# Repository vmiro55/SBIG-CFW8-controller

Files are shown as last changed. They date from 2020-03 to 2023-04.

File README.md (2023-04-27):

# SBIG-CFW8-controller
Arduino based controller for the CFW8 filter wheel manufactured by SBIG

The filter wheel will intialized to the first position when powered on.
In this case the first filter is RED. The filters in sequence are Red, Green, Blue, Luminance and an open spot (labeled clear in the code).

Change char *filter_color[] = {"Red", "Green", "Blue","Lumin.", "Clear"};  // change names to suit your setup.

Implemented serial support for communication with INDI, ASCOM...

## Serial communication description:

Sending a number from 1 to 5 ended with carriage return moves to appropriate filter and returns a filter name, for example:

'1\r' -> serial -> CFW

CFW -> 'Red' -> serial

Sending "9" retreives a current filter position:

'9\r' -> serial -> CFW 

CFW -> 'Red' -> serial

Any other number returns an error message:

'8\r' -> serial -> CFW 

CFW -> 'Error' -> serial

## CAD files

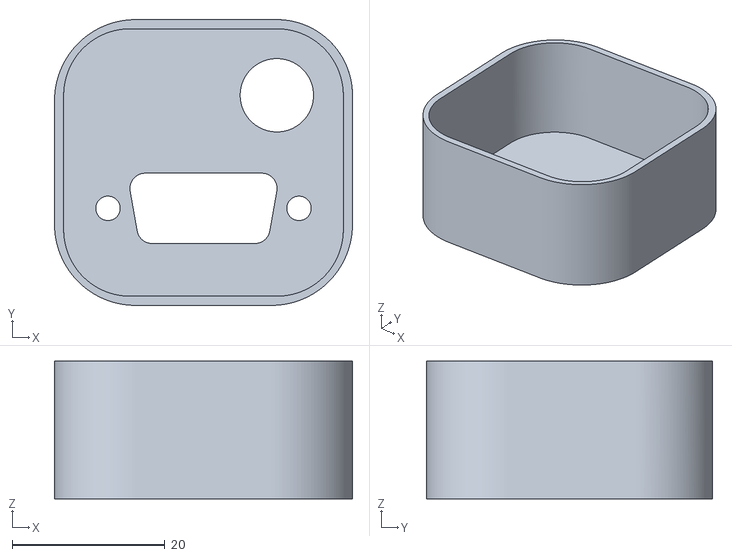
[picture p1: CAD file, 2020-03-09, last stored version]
CFW8 BOX TOP.stl
39.0 x 37.4 x 18.0

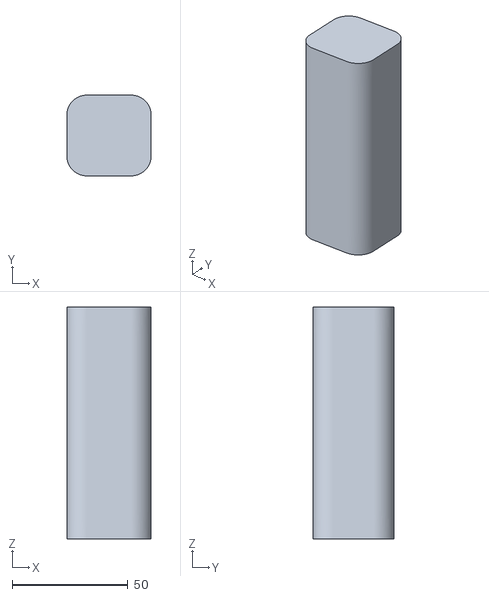
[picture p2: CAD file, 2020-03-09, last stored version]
CFW8 BOX.stl
36.4 x 34.8 x 100.0

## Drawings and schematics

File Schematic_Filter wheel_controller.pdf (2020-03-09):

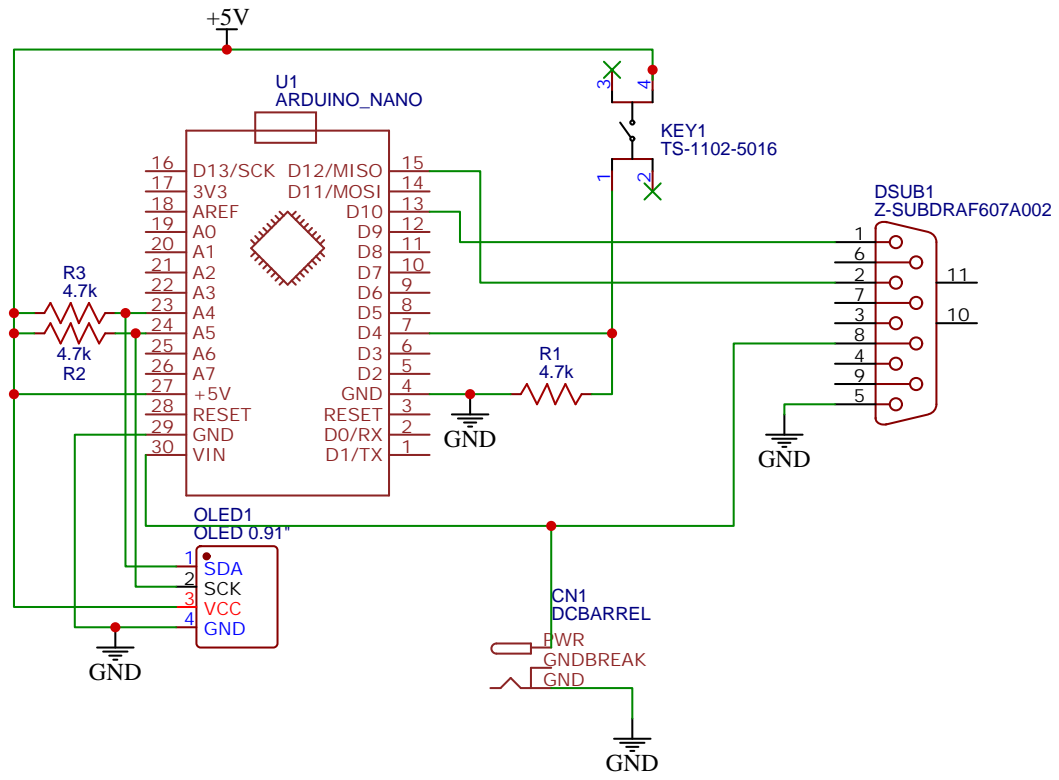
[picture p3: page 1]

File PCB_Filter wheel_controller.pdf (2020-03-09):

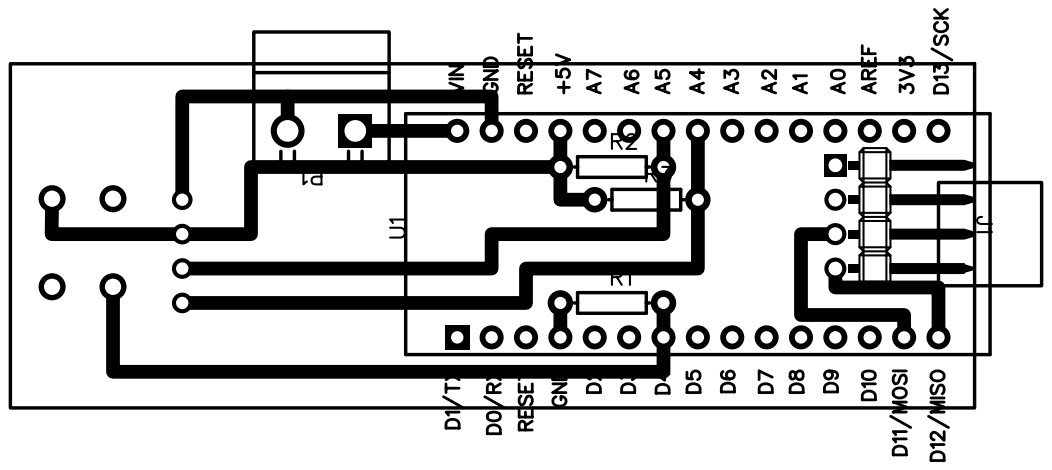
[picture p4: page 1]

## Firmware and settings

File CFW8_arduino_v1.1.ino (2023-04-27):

/*
SBIG CFW8 filter wheel controler By Ian Behar
Published under Creative Commons Zero v1.0 Universal liscence
french-toast74
Ian Behar March 2020
Miroslav Vukovic 2023
Version 1.1
*/

#include <Wire.h>
#include <Adafruit_GFX.h>
#include <Adafruit_SSD1306.h>

#define BUTTON_PIN 4
#define PULSE_OUT_PIN 12                          // The filter wheel Pulse Input pin
#define MOVE_COMPLETE_PIN 11                      // The filter wheel returns a TTL level low-going pulse on pin 1 while it is moving
#define MAX_SERIAL_CHAR 4
#define DEBUG 1

Adafruit_SSD1306 display = Adafruit_SSD1306(128, 32, &Wire);
int wheel_position = 1;
int selected_wheel_position = 1;
char *filter_color[] = {"Red", "Green", "Blue","Lumin.", "Clear"};       // Edit filter names as mounted on filter wheel from 1 to 5 (1 = Red if using SBIG's filter sequence set)
bool button_state = 0; 
bool last_button_state = 0;
bool move_flag = 0;
unsigned long next_millis = 0;
bool moving_state = 1;
bool last_moving_state = 1;
bool error_flag = 0;
int serialInput = 0;
char last_inSerial;


// Initialization: put your setup code here, to run once

void setup() {

display.begin(SSD1306_SWITCHCAPVCC, 0x3C);
pinMode(PULSE_OUT_PIN, OUTPUT);                   // Pin 2 on CFW 8 input for timing pulses
pinMode(BUTTON_PIN, INPUT);                       // Button Pin
pinMode(MOVE_COMPLETE_PIN, INPUT);                // Pin 1 on CFW 8 output active LOW indicates movement of filter wheel
Serial.begin(9600);                               // Initialize serial port

display.clearDisplay();
// delay(1000);

// on power up CFW 8 initializes to position 1 and makes a movment

next_millis = millis() + 4000;                                                    // setup 4 sec timeout
while(millis() < next_millis)
{
  moving_state = digitalRead(MOVE_COMPLETE_PIN);                                  // Read if wheel is moving, LOW = wheel is moving.
    if(moving_state != last_moving_state)                                         // If moving state changes enter the if statement
    { 
      if(moving_state == HIGH)                                                    // HIGH = movement is complete
      {
        PrintScreen(filter_color[wheel_position-1], 3);
        Serial.println(filter_color[wheel_position-1]); // DEBUG 
        error_flag = 0; // no errors go to void loop clears error/init condition
        next_millis = millis() - 1000; // init complete exit timeout loop (does this even work ?)
      }

      else                                                                        // Prints Init. while movement in progress or max 4 sec. Error flag will stay up is movement never completes
      { 
        error_flag = 1;
        PrintScreen("Init.", 2);
        Serial.println("Init.");
      }
    }
    last_moving_state = moving_state;
}
  if(error_flag)                                                                  // No movement prints error void loop has an infinite loop to prevent button presses
  {
    PrintScreen("ERROR!\nCheck FW connection \nor 12V power supply!", 1);
    Serial.println("ERROR! Check FW connection or 12V power supply!");
  }
  
  if(!error_flag)                                                                 // No errors, initialized go to void loop
  { };
}                                                                                 // End of setup()


// put your main code here, to run repeatedly:

void loop()
{
  digitalWrite(PULSE_OUT_PIN, LOW);             // Keep filter wheel command pin low while not in use (just in case)
  //if(error_flag){while(1){}}                  // enable for release!  inifinite loop is error during initializtion prevents button presses. 
  delay(50);
  selected_wheel_position = wheel_position;     // Prevents making movment when selecting the position the wheel is already in

// Detection of an input either from the button or from the serial input
  SerialCheck();
  ButtonCheck();

if(wheel_position == selected_wheel_position)                       // Don't move if you select the same position
{
  move_flag = 0;
}

if(move_flag == 1)
{
    //print_to_screen("Moving", 0,26); // prints moving (print again below but it takes some time, if theres an error it will go to error)
    PrintScreen("Moving", 2);
    // Serial.println("Moving"); //DEBUG
    filter_wheel_position(wheel_position, PULSE_OUT_PIN);                                     // Move the filter wheel!
    
    next_millis = millis() + 3000;                                                            // 8 sec move timeout
    while(millis() < next_millis)
    { 
      moving_state = digitalRead(MOVE_COMPLETE_PIN);                                          // Read if wheel is moving 
      if(moving_state != last_moving_state ){ 
        if(moving_state == HIGH)                                                              // Moving is COMPLETE    
        {                                                             
          PrintScreen(filter_color[wheel_position-1], 2);                                     // Print filter color
          error_flag = 0;                                                                     // No errors go to void loop clears error/init condition
          next_millis = millis() - 1000; // movement complete exit timeout loop 
        }
        
        else                                                                                  // Prints moving while movemnt in process or max 3 sec. error flag will stay up is movment never completes.
        {
          PrintScreen("Moving", 2);
          error_flag = 1;
          // Serial.println("Moving");
        } 
      }
      last_moving_state = moving_state;
   
    }
    
    if(error_flag)
    {
      PrintScreen("Moving", 2);
      // Serial.println("Moving");
    }
    
    if(!error_flag)                                                                           // print filter color if no errors proceed!
    {
      PrintScreen(filter_color[wheel_position-1], 2);
      Serial.println(filter_color[wheel_position-1]);
    } 
    
  }

  move_flag = 0; // clear moving message flag
}                                                                 // End of loop()
    
  //while(digitalRead(MOVE_COMPLETE_PIN) == LOW){ // locks code until move pin goes low
  //  }


// Button process

void ButtonCheck()
{
  button_state = digitalRead(BUTTON_PIN);

  if(button_state != last_button_state)
  {
    if(button_state == HIGH)
    {
      move_flag = 1;
      wheel_position++;
      if (wheel_position > 5)                                             // Reset position counter to not exceed 5
      { 
        wheel_position = 1;
      }

    PrintScreen(filter_color[wheel_position-1], 2);
    Serial.println(filter_color[wheel_position-1]); // DEBUG 
    }
    delay(50);
  }

  last_button_state = button_state;
}

// Serial data process
void SerialCheck() {
  int inserial;
  char inchar;
  
  while (Serial.available() > 0) {
    inchar = Serial.read();
        
    if (inchar == '\r') {
      if(inserial == 9) {
        Serial.println(filter_color[wheel_position-1]);
      }
      else if(inserial > 0 && inserial <= 5) {
        filter_wheel_position(inserial,PULSE_OUT_PIN);
        wheel_position = inserial;
        Serial.println(filter_color[inserial-1]);
        PrintScreen("Moving",2); PrintScreen(filter_color[inserial-1],2);
      }
      else {
        Serial.println("Error");
      }
    }
    else {
      inserial = inchar - '0';
    }
  }
}

//pwm_55(+Width in us, pin) 
void pwm_55(unsigned long wt, int pin){
  digitalWrite(pin, HIGH);
  delayMicroseconds(wt); // wt must be less than 2000us  
  digitalWrite(pin, LOW); 
  delay(16); //delayMicrosends can't be too long
  delayMicroseconds(2000-wt);
  }


// Move filter wheel to selected position 1 through 5 on output pin

void filter_wheel_position(int ps, int output_pin){
  unsigned long wt[5]={500, 800, 1100, 1400, 1700}; //500us filter 1, 800us filter 2, 1100us filter 3, 1400us filter 4, 1700us filter 5
  unsigned long next_micros = micros() + 1000000;
  while (micros() < next_micros) // repeat pwm_55 funtion for 1000000us (1s)
  {
    pwm_55(wt[ps-1], output_pin);
   }
}

void PrintScreen(char msg[], int size) {
  display.clearDisplay();
  display.setTextSize(size);                  // 1 for normal 1:1 pixel scale
  display.setTextColor(SSD1306_WHITE);        // Draw white text
  display.setCursor(0, 0);                    // Start at top-left corner
  display.println(msg);
  display.display();
}

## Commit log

2020-03-09 Add files via upload
    .stl files for a box to house the electronics
    [CFW8 BOX TOP.stl, CFW8 BOX.stl]
2020-03-09 Add files via upload
    CFW8 Filter wheel controller schematic
2020-03-09 Add files via upload
    Example layout for the circuit in the schematic
